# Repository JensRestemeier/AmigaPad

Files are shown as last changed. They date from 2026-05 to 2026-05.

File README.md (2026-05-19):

# AmigaPad
This is a copy of the schematic for the CD32 joypad from https://www.mrdictionary.net/PSCD32/diary/sites/CD32Gamepad_gerdkautzmann_de.html in KiCad, which is based on reverse engineered hardware.
I made a small PCB, which is mostly for testing and development work. So far I had no time to make a case for it.

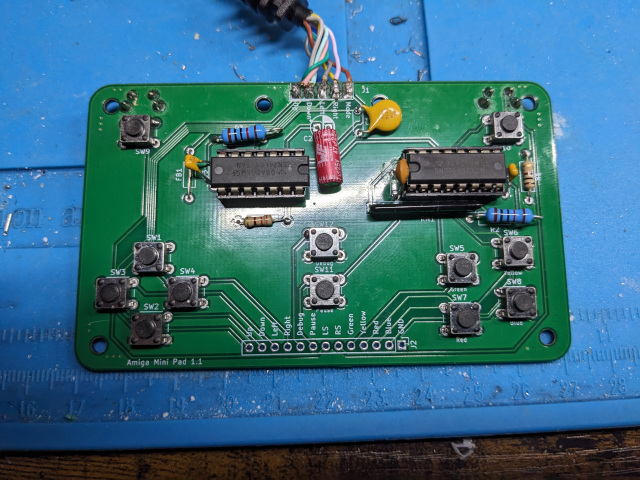
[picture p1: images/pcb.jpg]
Photo of a populated PCB


I don't know what kind of Ferrite Bead the original Joypad uses, so I just put in a bridge. There is a choice of populating vertical buttons for the shoulder buttons, or plain horizontal buttons on the component side. The button
above the start button has no function in a normal Amiga software.

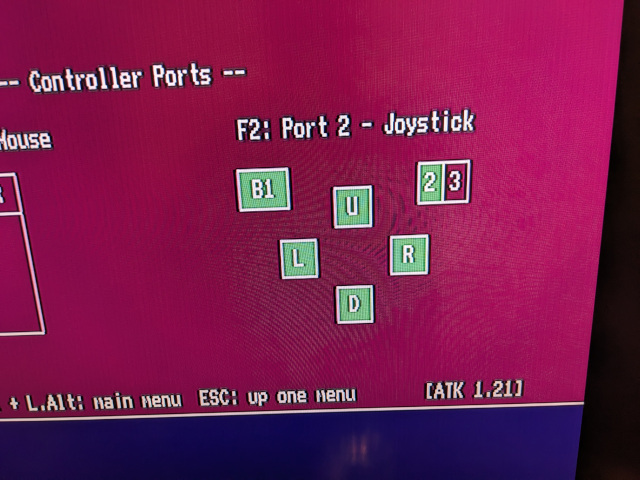
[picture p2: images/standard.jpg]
Photo of joystick mode in Amiga Test Kit


Classic Amiga software will see the directions, "red" as fire and "blue" as PotY.

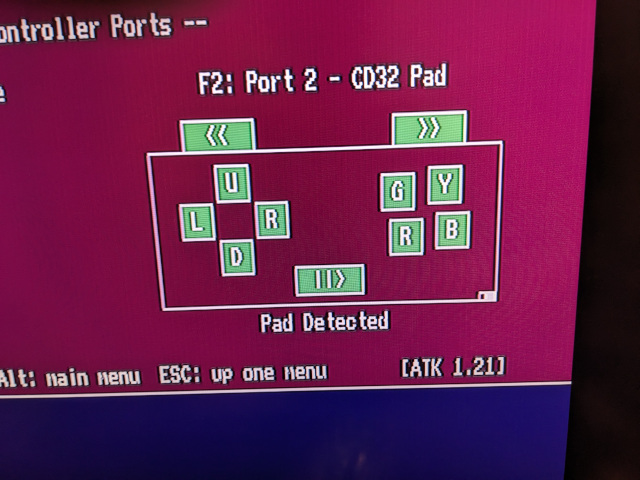
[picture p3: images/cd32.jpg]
Photo of CD32 mode in Amiga Test Kit


CD32-compatible software will see the directions, four face buttons, two shoulder buttons and a start button.

You can preview the KiCad project on [KiCanvas](https://kicanvas.org/?repo=https%3A%2F%2Fgithub.com%2FJensRestemeier%2FAmigaPad%2Ftree%2Fmain%2FKiCad).

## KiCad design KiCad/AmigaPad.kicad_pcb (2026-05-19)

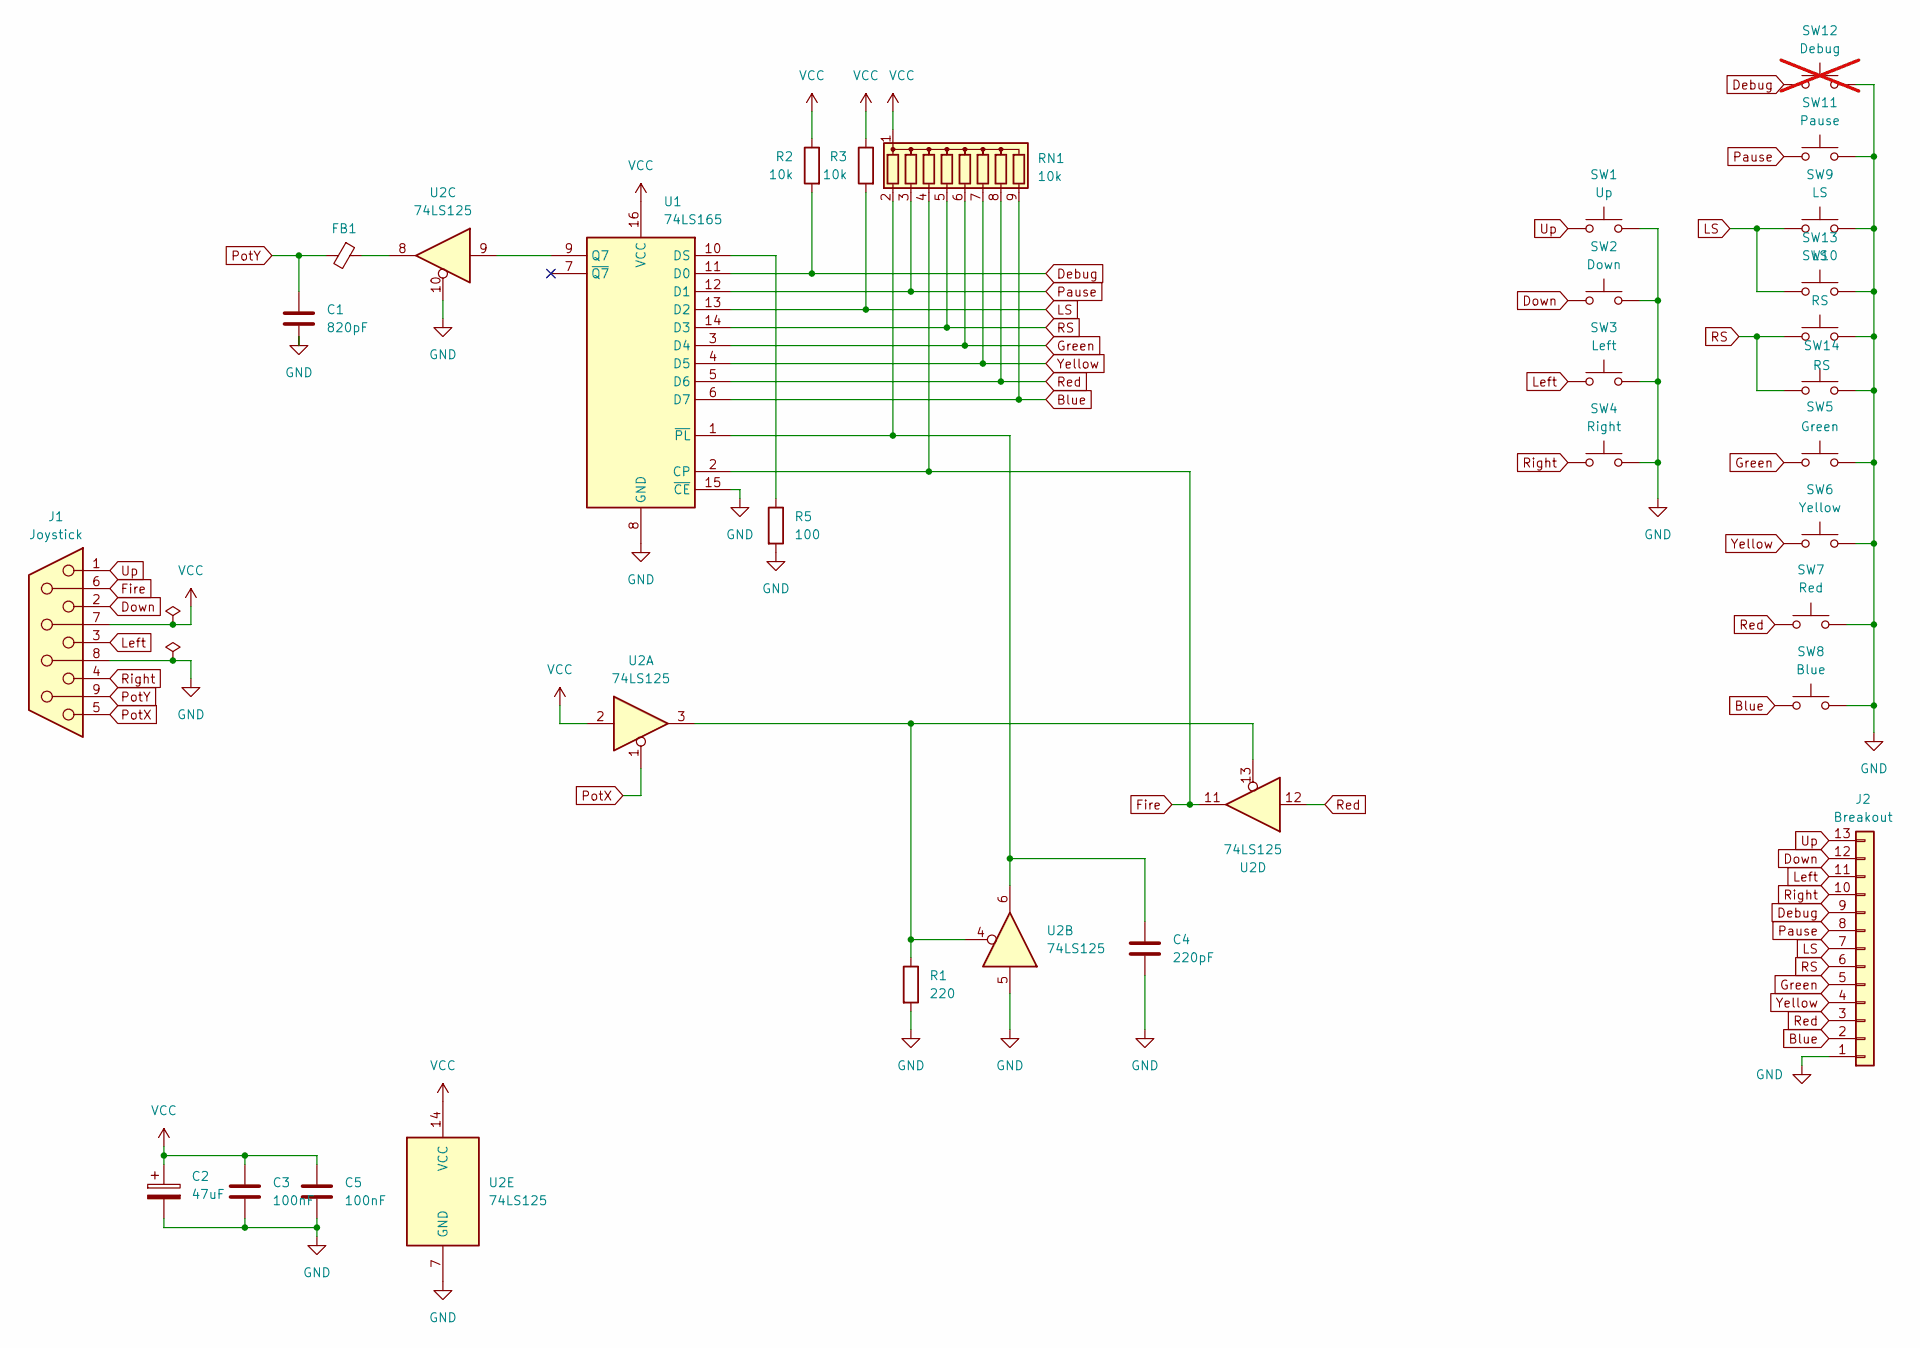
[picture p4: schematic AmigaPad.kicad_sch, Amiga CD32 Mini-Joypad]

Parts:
C1: 820pF; C_Disc_D4.3mm_W1.9mm_P5.00mm
C2: 47uF; CP_Radial_D5.0mm_P2.50mm
C3, C5: 100nF; C_Disc_D4.3mm_W1.9mm_P5.00mm
C4: 220pF; C_Disc_D4.3mm_W1.9mm_P5.00mm
FB1: FerriteBead_Small; L_Axial_L5.3mm_D2.2mm_P10.16mm_Horizontal_Vishay_IM-1
J1: Joystick; DSUB-9_Socket_EdgeMount_P2.77mm
J2: Breakout; PinHeader_1x13_P2.54mm_Vertical
R1: 220; R_Axial_DIN0207_L6.3mm_D2.5mm_P10.16mm_Horizontal
R2, R3: 10k; R_Axial_DIN0207_L6.3mm_D2.5mm_P10.16mm_Horizontal
R5: 100; R_Axial_DIN0207_L6.3mm_D2.5mm_P10.16mm_Horizontal
RN1: 10k; R_Array_SIP9
SW1: Up; SW_PUSH_6mm_H5mm
SW2: Down; SW_PUSH_6mm_H5mm
SW3: Left; SW_PUSH_6mm_H5mm
SW4: Right; SW_PUSH_6mm_H5mm
SW5: Green; SW_PUSH_6mm_H5mm
SW6: Yellow; SW_PUSH_6mm_H5mm
SW7: Red; SW_PUSH_6mm_H5mm
SW8: Blue; SW_PUSH_6mm_H5mm
SW9: LS; SW_PUSH_6mm_H5mm
SW10: RS; SW_PUSH_6mm_H5mm
SW11: Pause; SW_PUSH_6mm_H5mm
SW12: Debug; SW_PUSH_6mm_H5mm; not fitted
SW13: LS; SW_Tactile_SPST_Angled_PTS645Vx39-2LFS
SW14: RS; SW_Tactile_SPST_Angled_PTS645Vx39-2LFS
U1: 74LS165; DIP-16_W7.62mm
U2: 74LS125; DIP-14_W7.62mm

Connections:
Blue: J2.2, RN1.9 (R8), SW8.1, U1.6 (D7)
Debug: J2.9, R2.2, SW12.1, U1.11 (D0)
Down: J1.2, J2.12, SW2.1
Fire: J1.6, RN1.4 (R3), U1.2 (CP), U2.11
GND: C1.2, C2.2, C3.2, C4.2, C5.2, J1.8, J2.1, R1.2, R5.2, SW1.2, SW2.2, SW3.2, SW4.2, SW5.2, SW6.2, SW7.2, SW8.2, SW9.2, SW10.2, SW11.2, SW12.2, SW13.2, SW14.2, U1.8 (GND), U1.15 (~CE), U2.5, U2.7 (GND), U2.10
Green: J2.5, RN1.6 (R5), SW5.1, U1.3 (D4)
LS: J2.7, R3.2, SW9.1, SW13.1, U1.13 (D2)
Left: J1.3, J2.11, SW3.1
unnamed: FB1.1, U2.8
unnamed: R1.1, U2.3, U2.4, U2.13
unnamed: C4.1, RN1.2 (R1), U1.1 (~PL), U2.6
unnamed: R5.1, U1.10 (DS)
unnamed: U1.9 (Q7), U2.9
Pause: J2.8, RN1.3 (R2), SW11.1, U1.12 (D1)
PotX: J1.5, U2.1
PotY: C1.1, FB1.2, J1.9
RS: J2.6, RN1.5 (R4), SW10.1, SW14.1, U1.14 (D3)
Red: J2.3, RN1.8 (R7), SW7.1, U1.5 (D6), U2.12
Right: J1.4, J2.10, SW4.1
Up: J1.1, J2.13, SW1.1
VCC: C2.1, C3.1, C5.1, J1.7, R2.1, R3.1, RN1.1 (common), U1.16 (VCC), U2.2, U2.14 (VCC)
Yellow: J2.4, RN1.7 (R6), SW6.1, U1.4 (D5)

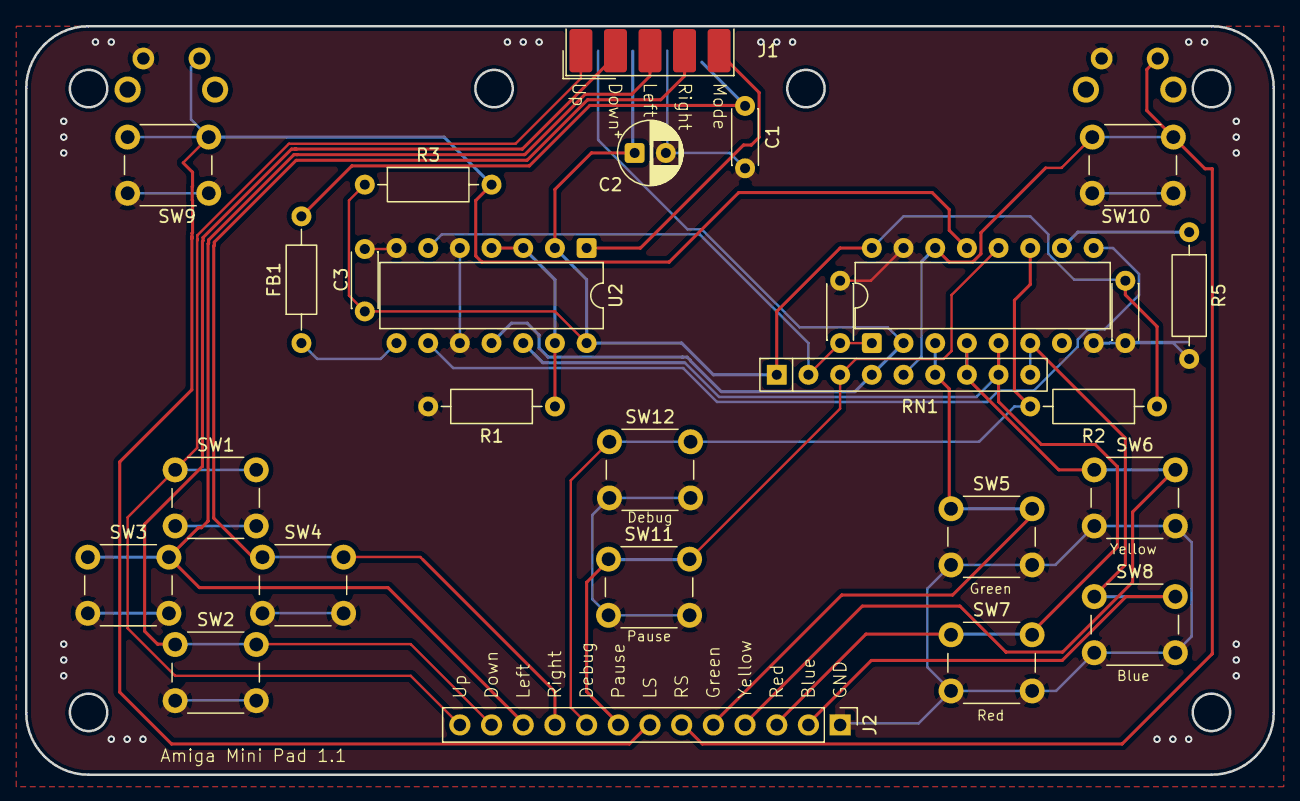
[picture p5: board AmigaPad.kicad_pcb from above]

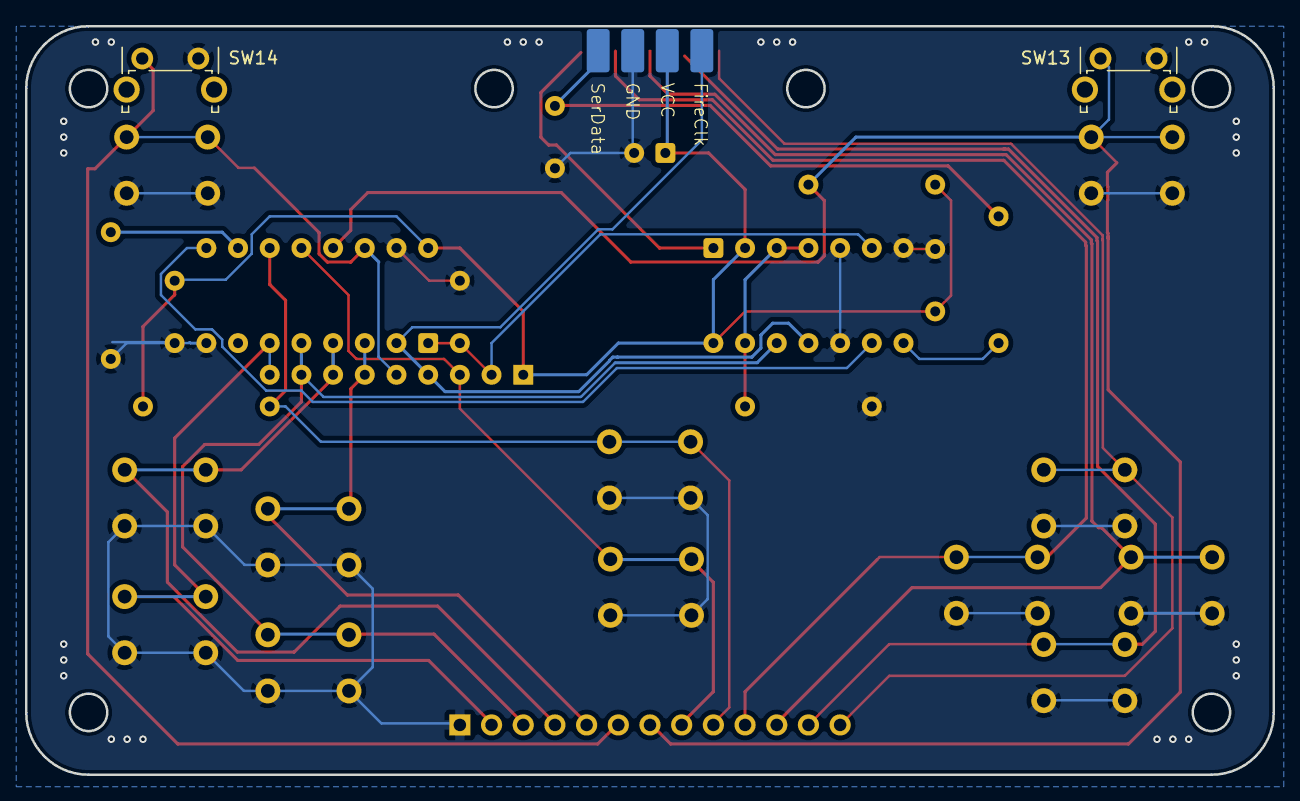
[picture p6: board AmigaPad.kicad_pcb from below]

Board: 2 copper layers, 100.0 x 60.0 mm, 29 parts (2 on the bottom side), 22 nets.
